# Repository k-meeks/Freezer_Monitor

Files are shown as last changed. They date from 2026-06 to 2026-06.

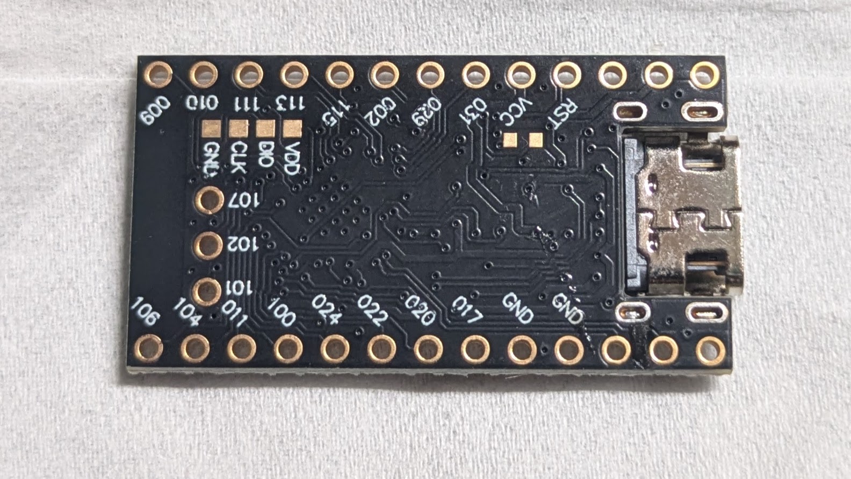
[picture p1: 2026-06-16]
reference-images/PXL_20260615_145303663.jpg

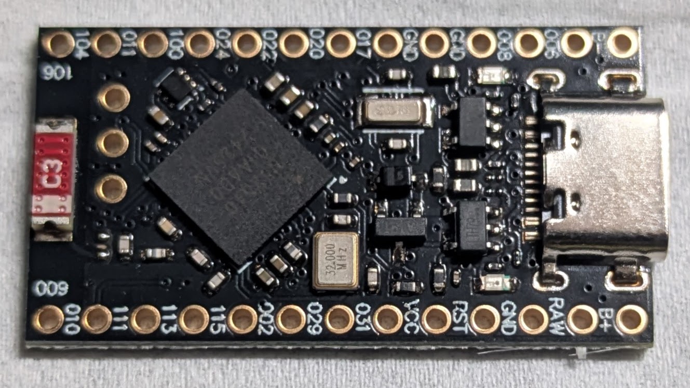
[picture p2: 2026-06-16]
reference-images/PXL_20260615_145255055.jpg

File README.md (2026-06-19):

# Freezer Monitor

A battery-powered sensor that lives inside a chest freezer and reports temperature to Home Assistant via Bluetooth.

## How it works

1. An **nRF52840** wakes on a timer, reads a **DS18B20** temperature sensor, measures battery voltage via an external resistor divider, and broadcasts both as a **BTHome v2** Bluetooth Low Energy advertisement.
2. **Home Assistant** (with a Bluetooth adapter) picks up the advertisement directly via its built-in BTHome integration — no gateway required if HA has BT access near the freezer.
3. HA exposes temperature and battery as entities for dashboards, automations, and alerting.

Power comes from a single Saft LS14250 cell (Li-SOCl₂, 3.6V, 1/2AA) — non-rechargeable, replaced manually when depleted.

## Status

**Deployed and running live** — board is inside the freezer, waking every 5 minutes, with battery and temperature tracked continuously in HA.

**Range note:** Chest freezer lids significantly attenuate BLE (observed drop from -54 dBm on the desk to -82/-88 dBm inside the freezer). TX power is set to +8 dBm (nRF52840 max) to compensate. The active bridge for range is [linux_bt_proxy](https://github.com/k-meeks/linux_bt_proxy) — a fork running on a Linux host near the freezer that relays BTHome advertisements to HA. Theengs Gateway (`ha-bridge/`) remains an untested fallback if that proxy path ever has issues.

A carrier PCB design is in progress — see [Carrier PCB](#carrier-pcb) below.

---

## Parts list

| Part | Spec / notes |
|---|---|
| nRF52840 board | Teyleten Pro Micro nRF52840 (nice!nano v2 clone, ~$4) |
| Temperature sensor | DS18B20 (waterproof probe recommended for freezer use) |
| Battery | Saft LS14250 — Li-SOCl₂, 3.6V nominal, 1/2AA, **primary/non-rechargeable** |
| Battery holder | 1/2AA holder with leads, or JST pigtail — wire through a connector, not direct solder |
| Pull-up resistor | 4.7kΩ (DS18B20 data line) |
| Divider resistors | 2× ~1MΩ (battery voltage sense) |
| Debug adapter | CP2102 or CH340 USB-to-serial, 3.3V logic (development only) |

---

## Board pinout

The board has two 13-pin header rows. **Pin 1 = end farthest from the USB-C connector. Pin 13 = the B−/B+ battery pad itself.**

```
                    USB-C connector
                         |||
         Left (B− side)       Right (B+ side)
         ──────────────       ───────────────
  13     B−  ←battery−        B+  ←battery+       13
  12     P0.06  Serial1 TX    RAW  (USB rail)      12
  11     P0.08  Serial1 RX    GND                  11
  10     GND                  RST  (reset)         10
   9     GND                  VCC  (unusable on    9
                                    battery only)
   8     P0.17  I2C SDA       P0.31 / A7           8
   7     P0.20  I2C SCL       P0.29 / A5           7
   6     P0.22                P0.02 / A0  ←divider 6
   5     P0.24  ←DS18B20      P1.15                5
   4     P1.00                P1.13  SPI SCK        4
   3     P0.11                P1.11  SPI MISO       3
   2     P1.04                P0.10  NFC2/SPI MOSI  2
   1     P1.06                P0.09  NFC1            1
```

**Known-bad pins — do not use:**
- P0.14, P0.16: hang/crash-loop the board when configured as GPIO
- P0.13: not connected to any header pin on this board
- VCC (right pos 9): reads ~0V when running on battery only

---

## Wiring

### Battery (LS14250)

```
LS14250 +  →  B+  (right side, pos 13)
LS14250 −  →  B−  (left side, pos 13)
```

> **Safety:** The board's onboard charge IC is wired to B+/B−. Li-SOCl₂ cells
> must never receive charge current — this is a fire/rupture hazard.
> **Never connect USB while the LS14250 is wired to B+/B−.**
> Wire the cell through a connector (header pins, JST) so it can be unplugged
> before any USB connection.

---

### DS18B20 temperature sensor

The DS18B20 probe has three wires:

```
Red   (VDD)   →  B+  (right side, pos 13)
Black (GND)   →  B−  (left side, pos 13)
Yellow (data) →  P0.24  (left side, pos 5)

4.7kΩ pull-up resistor between yellow (data) and red (VDD/B+)
  — NOT to GND. The data line must be pulled up to VDD, not ground.
```

The easiest way to install the pull-up: bridge the resistor between the yellow
and red wires right at the point where they enter the board headers.

---

### Battery voltage divider

Two ~1MΩ resistors in series form a voltage divider from B+ to GND. The
midpoint is tapped to an ADC input so the firmware can read battery voltage.

```
B+  (right side, pos 13)
  │
 [1MΩ]
  │
  ├──→  P0.02 / A0  (right side, pos 6)
  │
 [1MΩ]
  │
GND  (left side, pos 9 or 10, or right side pos 11)
```

Practical assembly: twist the two resistors together end-to-end. One free end
goes to B+, the other free end goes to GND, and the junction (where they meet)
goes to P0.02/A0 (right side, pos 6).

Continuous draw: ~1.8µA — negligible against the LS14250's 1200mAh capacity.

---

### Debug serial (development only)

When debugging on battery (USB disconnected), use a CP2102/CH340 USB-to-serial
adapter wired to Serial1:

```
Board TX  (left side, pos 12 / P0.06)  →  Adapter RX
Board GND (left side, pos 9 or 10)     →  Adapter GND
Adapter TX pin                          →  leave disconnected
Adapter power/VCC pin                   →  leave disconnected
```

The adapter gets its own USB connection to the PC. The board stays on battery.
Baud rate: 115200.

---

## Arduino IDE setup

1. **File → Preferences → Additional Boards Manager URLs**, add both:
   - `https://adafruit.github.io/arduino-board-index/package_adafruit_index.json`
   - `https://github.com/jpconstantineau/Community_nRF52_Arduino/releases/latest/download/package_jpconstantineau_boards_index.json`
2. **Boards Manager**: install **Adafruit nRF52**, then **Community Add on Adafruit nrf52 boards**.
3. Select board: **Nice Keyboard's nice!nano** (from the Community package).
4. Install libraries: **OneWire**, **DallasTemperature** (Bluefruit BLE is included with the Adafruit nRF52 core).
5. Open `firmware/freezer_monitor/freezer_monitor.ino`.

---

## Programming workflow

Because B+/B− is the charge IC input, flashing and running on the LS14250
cannot happen at the same time:

1. Disconnect the LS14250 from B+/B−.
2. Connect USB, flash firmware from Arduino IDE.
3. Disconnect USB.
4. Reconnect the LS14250.

To enter the UF2 bootloader manually: double-tap the RST pin (right side,
pos 10) — the onboard LED will fade in/out when the bootloader is active.

---

## Home Assistant setup

1. Ensure HA has Bluetooth hardware (built-in adapter or an ESPHome BT proxy).
2. **Settings → Devices & Services → Add Integration → BTHome**.
3. HA will discover the device (`FreezerMonitor`) within a few seconds.
4. The device exposes: temperature (°C), battery (%), packet ID.

> **Range note:** Chest freezer metal lids significantly attenuate BLE signal.
> This deployment uses [linux_bt_proxy](https://github.com/k-meeks/linux_bt_proxy)
> on a nearby Linux host to relay BTHome advertisements to HA. Theengs Gateway
> (`ha-bridge/`) is an untested fallback if that proxy path ever has issues.

---

---

## Carrier PCB

A KiCad carrier board sockets the nRF52840 module into machine-pin headers; all peripherals connect via JST-PH connectors; passives (pull-up, voltage divider, bulk cap) are placed components on the board.

### Bill of materials

PCB-side components (driven by `COMPONENTS` in `gen_freezer_netlist.py`):

| Ref | Qty | Part | Value / spec | Package | Notes |
|---|---|---|---|---|---|
| U1 | 1 | nice!nano nRF52840 (Teyleten clone) | — | THT, 2×13 @ 2.54mm | Socketed, not soldered directly — see machine-pin headers below |
| BT1 | 1 | Battery holder | Keystone 1011, 1/2AA | THT | Polarity-keyed; footprint from SnapEDA (`pcb_build/1011/`) |
| R1, R2 | 2 | Resistor | 1MΩ | 0805 | Battery voltage divider |
| R3 | 1 | Resistor | 4.7kΩ | 0805 | DS18B20 OneWire pull-up to VBAT (not 3.3V) |
| C1 | 1 | Aluminum-polymer radial capacitor | 100µF, low-ESR/low-leakage, ≥6.3V | THT, 8mm dia, 3.5mm lead pitch | Bulk cap at the cell terminals — absorbs BLE TX current spikes against the LS14250's high internal impedance |
| C2 | 1 | Ceramic capacitor | 10nF | 0805 | ADC sense-node decoupling at P0.02 |
| J1 | 1 | JST PH receptacle, 3-pos | B3B-PH-K | THT, 2.00mm pitch | DS18B20 connector |
| J2 | 1 | Pin header, 1×4 | — | THT, 2.54mm | Debug UART: GND / VCC / TX / RX |
| JP1 | 1 | Pin header, 1×2 | — | THT, 2.54mm | Battery isolation jumper — pull before connecting USB |

Off-netlist items needed to finish the build:

| Item | Qty | Notes |
|---|---|---|
| Saft LS14250 cell | 1 | Drops into BT1 — see [Battery (LS14250)](#battery-ls14250) safety note |
| Machine-pin (turned-pin) header strip, 2.54mm | 2× 1×13 | Sockets for U1 so the module can be swapped without desoldering |
| 2.54mm jumper shunt | 1 | For JP1 |
| JST PH 3-pos plug + crimp pins (or pre-crimped pigtail) | 1 | Mates with J1 — only needed if your DS18B20 probe isn't already terminated with one |
| 2-pin or 4-pin 2.54mm header mate | 1 (optional) | For a CP2102/CH340 debug adapter — development only |

All SMD passives are 0805 to keep hand-soldering reasonable without hot air.

### Generating the design files

Regenerate the netlist after any connectivity change:

```
python3 gen_freezer_netlist.py
```

Regenerate the U1 footprint (only needed if the physical module's pinout or dimensions change):

```
python3 gen_nicenano_footprint.py
```

This writes `nice_nano_teyleten.kicad_mod`. To mount U1 rotated 180° (USB/B+/B- end at the opposite side of the board), rotate the footprint instance in pcbnew — that's a placement choice, not something the generator needs to encode.

**Key design decisions baked into the netlist:**
- `JP1` interrupts the battery positive rail — pull the jumper before connecting USB for reprogramming
- `R3` (4.7kΩ) pulls DS18B20 data to VBAT, not 3.3V — sensor is powered from the cell directly
- `C1` (100µF low-ESR electrolytic) at the cell terminals dampens the LS14250's high internal impedance under BLE TX bursts
- `C2` (10nF) decouples the ADC sense node at P0.02
- J2 pin 2 (VCC) is sourced from P1.06 held HIGH — provides a 3.3V logic reference for the CP2102 debug adapter without requiring VCC rail (which is unavailable on battery-only power)

> **Footprint warning:** The netlist uses functional pad names (`B+`, `B-`, `P0.24`, etc.) for U1. Verify these match the exact pad names in `nice!nano clone:nice_nano_teyleten` (or whatever footprint you assign to U1) before importing into KiCad — a mismatch silently drops the connection with no DRC error.

---

## External alerting (planned)

Not yet built — this section documents the intended design so it doesn't get lost between sessions.

**Goal:** when something silently goes wrong (power outage, dead battery, freezer warming up, or HA itself going down), get a phone call or text to a real person — not just a dashboard nobody's looking at.

**Architecture:**

```
nRF52840 (BTHome over BLE)
        │
        ├─ HA host w/ BT  ──┐
        │                   │   POST {site_id, temperature, battery, timestamp}
        └─ ESP32 BLE bridge ┘        (for homes without HA)
                            │
                            ▼
                Alerting API (GCP, TLS + API key)
                            │
                per-site rule evaluation
                            │
                      voip.ms (SMS / call)
```

Designed to scale beyond one freezer in one house — family members could each run their own monitor with their own contact info and thresholds.

**Per-site config** is a hand-edited YAML file, one entry per site, with a variable-length list of alert rules so each owner can have as many or as few thresholds as they want:

```yaml
sites:
  - id: FreezerMonitor-Kyle
    owner: Kyle
    phone: "+1..."
    expected_interval_minutes: 5
    setpoint_c: -18
    rules:
      - {id: missing_10, metric: missing_events, threshold: 10, action: call, repeat: every_1h}
      - {id: temp_5,      metric: temp_delta_c,   threshold: 5,  action: call, repeat: every_1h}
      - {id: battery_30,  metric: battery_pct,    threshold: 30, action: sms,  repeat: once}
      - {id: battery_15,  metric: battery_pct,    threshold: 15, action: sms,  repeat: once}
      - {id: battery_5,   metric: battery_pct,    threshold: 5,  action: call, repeat: every_1h}
```

Each rule fires independently on its own schedule (`once`, or `every_Nh` to keep repeating until resolved), tracked per `(site_id, rule_id)` rather than list position, since rules can be added or reordered later.

**Two alert types:**
- **Heartbeat/watchdog** — missing check-ins, a proxy for power or connectivity failure (there's no direct power sensor). Needs no event log: one `last_seen_at` timestamp per site, compared against `expected_interval_minutes × threshold` cycles.
- **Condition alerts** — temperature too far above setpoint, or battery below a tier threshold. Only meaningful while the device is actively reporting.

**Auth:** the API key lives at the bridge (an HA secret, or baked into ESP32 bridge firmware/config) — never inside the BTHome BLE payload itself, since BLE advertisements broadcast in the clear and there's no spare room in the ~31-byte legacy advertising payload anyway. TLS is required for the API regardless of which bridge is talking to it.

**Still undecided:** exact `/events`/`/check` endpoint contracts, ESP32 bridge firmware specifics, voip.ms integration details, whether to send an "all-clear" notice when an alert resolves.

---

## Repository layout

```
firmware/
  freezer_monitor/     Main Arduino sketch (temperature + BTHome v2 advertisement)
  board_bringup/       Diagnostic sketch used during hardware bring-up (historical)
gen_freezer_netlist.py KiCad netlist generator for the carrier PCB
freezer_monitor.net    Generated KiCad netlist (regenerate via gen_freezer_netlist.py)
ha-bridge/             Theengs Gateway docker-compose (untested fallback; active bridge is linux_bt_proxy, a separate repo)
docs/
  bthome/              BTHome v2 format reference
  hardware/            Board pinout, confirmed quirks, battery notes
  home-assistant/      HA REST API reference
```

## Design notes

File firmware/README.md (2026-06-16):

# Firmware

Arduino sketch for the nRF52840 (Adafruit nRF52 BSP).

Responsibilities:
- Read temperature from the DS18B20 (OneWire / DallasTemperature)
- Read battery voltage/level
- Assemble and send a BTHome v2 BLE advertisement
- Sleep between readings to conserve the 14250 cell

Not yet implemented.

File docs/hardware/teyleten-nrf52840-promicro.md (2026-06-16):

# Teyleten Pro Micro nRF52840 (nice!nano v2 clone)

Saved: 2026-06-15. Compiled from web research — items marked **UNVERIFIED** have not
yet been confirmed against the actual board and should be checked once hardware is
in hand. Move confirmed items to CLAUDE.md's "confirmed quirks" section once tested.

## Identity

- Sold as "Teyleten Robot Pro Micro NRF52840", ~$4, nice!nano v2 form-factor clone.
- Generic family also known as "SuperMini nRF52840" / "Pro Micro nRF52840".
- Zephyr board name for this family: `promicro_nrf52840` (marked "not actively
  maintained" — treat as a loose reference, not gospel).
- Ships with Adafruit's UF2 bootloader.

## Sources

- Pinout notes (community-tested): https://github.com/longrackslabs/teyleten-nrf52840-pinout
- Zephyr board doc: https://docs.zephyrproject.org/latest/boards/others/promicro_nrf52840/doc/index.html
- nice!nano pinout/schematic: https://nicekeyboards.com/docs/nice-nano/pinout-schematic/
- nice!nano battery measurement differences (v1 vs v2): https://github.com/joric/nrfmicro/wiki/Batteries
- Community Arduino board package: https://github.com/jpconstantineau/Community_nRF52_Arduino

## Arduino IDE setup

1. Add both URLs to **File > Preferences > Additional Boards Manager URLs**:
   - `https://adafruit.github.io/arduino-board-index/package_adafruit_index.json` (official Adafruit nRF52 core — required base package)
   - `https://github.com/jpconstantineau/Community_nRF52_Arduino/releases/latest/download/package_jpconstantineau_boards_index.json` (community add-on, adds nice!nano-family boards)
2. In Boards Manager, install **Adafruit nRF52** first, then the community package
   listed as **"Community Add on Adafruit nrf52 boards"** — it appears at the bottom
   of the board list.
3. **CONFIRMED (2026-06-15)**: select **"Nice Keyboard's nice!nano"** (`nice_nano`,
   from `community_nrf52` package v0.1.21). This matches the Teyleten board's
   physical Pro Micro/nice!nano form factor and its `variant.h` defines a `PIN_VBAT`
   (see Battery section below). Build settings: `nice_nano.build.vid=0x239A`,
   `pid=0x00B3`, `upload.maximum_size=815104`.
4. **CONFIRMED**: the board's bootloader reports via USB as VID `0x239A` / PID
   `0x8029` (Tools > Get Board Info shows "Adafruit Feather nRF52840 Express") —
   this exactly matches the `feather52840` entry in the Adafruit package. Despite
   the declared PID differing from `nice_nano`'s (`0x00B3`), both boards use
   `upload.tool=nrfutil` with the same `upload.maximum_size=815104` (same SoftDevice
   S140 6.1.1 layout), so selecting `nice_nano` for build/upload should still work —
   the 1200bps-touch DFU reset doesn't depend on the declared PID matching. If
   upload fails, fall back to building as `feather52840` and only use `nice_nano`
   for the variant.h pin reference.
5. To flash: double-tap the reset button to enter UF2 bootloader mode (status LED
   fades in/out when active), then upload from Arduino IDE (or drag-and-drop the
   `.uf2`).

## Pin numbering convention

From community pin-discovery testing, **confirmed** by the `nice_nano` variant.h
(`_PINNUM(port, pin) = port*32 + pin`):
- `P0.xx` = Arduino pin number `xx` (for xx = 0–31)
- `P1.xx` = Arduino pin number `32 + xx` (for xx = 0–15, i.e. Arduino pins 32–47)

## `nice_nano` variant.h pin reference (confirmed, from installed package v0.1.21)

- `PIN_LED1` (blue) = P0.15 = pin 15 — matches Zephyr `promicro_nrf52840` LED0.
- `PIN_VBAT` = `A7` = pin 31 (P0.31) — see Battery section below.
- Analog: A0-A3 = pins 2-5 (P0.02-P0.05), A4-A7 = pins 28-31 (P0.28-P0.31). `PIN_AREF` = pin 2 (shared with A0).
- Serial1: RX = pin 8 (P0.08), TX = pin 6 (P0.06)
- SPI: MISO = pin 43 (P1.11), MOSI = pin 10 (P0.10), SCK = pin 45 (P1.13)
- Wire: SDA = pin 17 (P0.17), SCL = pin 20 (P0.20)
- NFC1/NFC2 = P0.09 / P0.10 (shared with SPI MOSI when NFC disabled)
- BUTTON_1 = P0.18 marked "unusable: RESET"; BUTTON_2 = P0.19 "no connection" — avoid both.
- `ADC_RESOLUTION` = 14 bits.

## Quick pin reference (silkscreen label -> function)

The silkscreen prints the raw `P0.xx`/`P1.xx` number (with leading zeros, no
"P0." prefix) — e.g. the pin labeled `006` is P0.06. There are no TX/RX/A0-style
function labels printed on the board. For functions used in this project:

| Silkscreen label | Pin / function |
|---|---|
| `B+` | Battery positive (LS14250 +) |
| `B-` | Battery negative (LS14250 -) |
| `006` | P0.06 = `Serial1` TX (debug UART, see below) |
| `008` | P0.08 = `Serial1` RX |
| `007` | P0.07 = OneWire/DS18B20 data (firmware `ONEWIRE_PIN`) |
| `013` | P0.13 = sensor rail power switch (firmware `SENSOR_PWR_PIN`) |
| `031` | P0.31 = A7 = `PIN_VBAT` candidate |
| `VCC` | Regulated 3.3V output |
| `RAW` | Unregulated USB-side rail (not `B+` — don't confuse) |
| `GND` | Ground (multiple) |
| (not exposed) | P0.04 = A2 = alternate VBAT candidate (internal only) |

## Physical board pinout (CONFIRMED 2026-06-15, from board photos)

Top side (USB-C connector), bottom edge of header, right-to-left from the
connector corner: **`B+`**, `RAW`, `GND`, `RST`, `VCC`, `031`, `029`, `002`, ...
Top edge of header, same corner: **`B-`**, `006`, `008`, `GND`, `GND`, `017`, ...

- **`B+` / `B-`** — the battery connection pads. This is the only battery input
  exposed on this board (no separate charge-bypass pad). See Battery section
  below for wiring and safety implications.
- **`RAW`** — unregulated USB-side rail (VBUS-derived), distinct from `B+`. Do
  not confuse the two.
- **`VCC`** — regulated 3.3V output.
- **`031`** = P0.31 = `PIN_VBAT`/A7 (matches variant.h, see Battery voltage
  monitoring section).
- Back side of the board has a 4-pad cluster silkscreened `GND` / `CLK` / (one
  more) / `VDD` near the top edge — likely a debug/SWD header. Not needed for
  current work; useful if firmware debugging via SWD is ever required.

## Physical pin reference (1-13 per side)

Simpler than reading silkscreen labels: each header row has 13 pins. **Pin 1 =
the end farthest from the USB-C connector, pin 13 = the `B-`/`B+` pad itself.**

| Pos | Left side (B- side) | Right side (B+ side) |
|---|---|---|
| 1 | P1.06 — GPIO, no special function | P0.09 — GPIO / NFC1 |
| 2 | P1.04 — GPIO, no special function | P0.10 — GPIO / NFC2, SPI MOSI |
| 3 | P0.11 — GPIO, no special function | P1.11 — SPI MISO |
| 4 | P1.00 — GPIO, no special function | P1.13 — SPI SCK |
| 5 | P0.24 — GPIO, no special function | P1.15 — GPIO, no special function |
| 6 | P0.22 — GPIO, no special function | P0.02 — A0 / AREF |
| 7 | P0.20 — I2C SCL | P0.29 — A5 |
| 8 | P0.17 — I2C SDA | P0.31 — A7 / `PIN_VBAT` |
| 9 | GND | VCC — regulated 3.3V output (USB/RAW-derived, see below) |
| 10 | GND | RST — reset |
| 11 | P0.08 — Serial1 RX | GND |
| 12 | P0.06 — Serial1 TX | RAW — unregulated USB/VBUS rail |
| 13 | **B-** — battery negative | **B+** — battery positive |

Notes:
- P0.15 (`PIN_LED1`, onboard blue LED) is not in this table — it's an onboard
  component, not broken out to a header pin.
- P0.13 also doesn't appear in this table — see "Known special pins" below.
  P0.07 (the original OneWire pin choice) had the same problem; firmware now
  uses P0.24 (left side, position 5) instead.

## Known special pins

- **P0.13** — **CONFIRMED 2026-06-15: not broken out on this board's header at
  all.** `digitalWrite(13, ...)` has no observable effect on `VCC` or any
  header pin (tested via `firmware/board_bringup/board_bringup.ino`: B+ read
  3.6V correctly via multimeter, confirming the meter/ground setup was good,
  but `VCC` stayed near 0V regardless of P0.13 state, and right-side positions
  3-5 all read flat ~45mV noise regardless of P0.13 state). Originally planned
  as `SENSOR_PWR_PIN` for DS18B20 power-gating — dropped; DS18B20 now wires
  directly to `B+`/`B-`.
- **P0.14, P0.16** — **CONFIRMED 2026-06-15: both hang/crash-loop the board**
  as soon as either is configured as GPIO (`pinMode`/`digitalWrite`). Do not
  use either pin.
- **`VCC` (right side, position 9)** — **CONFIRMED 2026-06-15: reads ~0V when
  running off `B+` alone**, regardless of P0.13 state. Likely fed from a
  USB/RAW-derived regulator rather than the battery — not usable as a
  peripheral supply rail on battery power.
- **LED0 = P0.15** (per Zephyr `promicro_nrf52840` board doc) — onboard only,
  not a header pin.

## Battery cell: Saft LS14250 (Li-SOCl2, primary/non-rechargeable)

**CONFIRMED 2026-06-15**: the cell in use is a Saft LS14250 — Lithium Thionyl
Chloride, 1/2AA, 3.6V nominal, primary (non-rechargeable). This is NOT the
Li-ion/LiPo chemistry the onboard charge IC (e.g. BQ24072 on nice!nano-family
boards) expects.

- **Do not let the onboard charge circuit attempt to charge this cell.** Li-SOCl2
  cells can vent, rupture, or ignite under reverse/charge current — this is a
  safety issue, not just a degradation one.
- **CONFIRMED 2026-06-15**: `B+`/`B-` (see "Physical board pinout" above) is the
  only battery input on this board — there is no separate charge-bypass pad.
  Charging only engages when USB power is present (the charge IC is powered from
  VBUS), so the operating rule is: **never plug in USB while the LS14250 is
  connected to B+/B-**. Wire the cell through a connector (JST pigtail + holder
  or a 2-pin header), not a permanent solder joint, so it can be unplugged before
  any USB connection (reprogramming, debugging).
- Wiring: **LS14250 positive lead → `B+`, negative lead → `B-`**. Double-check
  polarity against the cell's own markings before connecting — reverse polarity
  into a charge IC input is its own hazard.

### Debugging while battery-powered

The board's own `Serial` (USB CDC) is only usable when its USB port is
connected — which conflicts with the LS14250-on-`B+`/`B-` rule above. For any
test that needs the battery actually powering the board (e.g. reading
`PIN_VBAT`/A2 against a real battery voltage), use **`Serial1`** (hardware
UART, TX = pin 6/P0.06) wired to a separate 3.3V USB-to-serial adapter
(FTDI/CP2102/CH340): board TX → adapter RX, GND → GND, adapter power pin left
disconnected. The adapter gets its own USB connection to the PC; the board
stays on battery only. `firmware/board_bringup/board_bringup.ino` prints to
both `Serial` and `Serial1` for this reason.

### Programming workflow with the LS14250 connected

Because `B+`/`B-` is the charge IC's input, flashing (which requires USB) and
running on the LS14250 can't happen at the same time. Workflow:

1. Disconnect the LS14250 from `B+`/`B-`.
2. Connect USB, flash firmware.
3. Disconnect USB.
4. Reconnect the LS14250 to run standalone.

**CONFIRMED 2026-06-15**: with only the LS14250 on `B+`/`B-` (no USB, no
firmware flashed yet), the board powered up and a red LED (near a GND pin —
not near the USB connector/charge IC) slow-flashed. This is consistent with
the UF2 bootloader's idle pattern on a board with no application yet, and
confirms `B+`/`B-` wiring powers the board correctly. Not a charge-IC fault
indicator — that would be expected near the USB connector and requires USB
power to occur at all.

Wire the battery through a connector (2-pin header + jumper, or JST pigtail),
not a permanent solder joint, so steps 1 and 4 are quick during development.
- "Recharge" is replaced by "swap the cell" for this project. LS14250 has very
  low self-discharge and is commonly used in devices needing years of service
  from one cell (water meters, alarms), so this is a reasonable tradeoff.
- Li-SOCl2 has a very flat discharge voltage curve until near end-of-life, then
  drops sharply. A voltage-based battery % will read near-100% for most of the
  cell's life and then fall quickly — see [[project-failure-alerting]] for how
  this affects alerting design, and "Battery voltage monitoring" below for how
  it's measured on this board.

## Battery voltage monitoring

- **CONFIRMED 2026-06-15**: `PIN_VBAT`/A7 (P0.31) and A2 (P0.04) are both
  floating/unconnected on this clone — `analogRead()` on either returns pure
  noise uncorrelated with actual battery voltage. There is no internal VBAT
  divider on this board.
- **Solution: external resistor divider.** Two ~1MΩ resistors in series from
  `B+` to `GND`, midpoint wired to `P0.02`/A0 (right side, position 6). Per
  https://devzone.nordicsemi.com/nordic/nordic-blog/b/blog/posts/measuring-lithium-battery-voltage-with-nrf52
  this is the standard approach when no internal divider is present. Adds
  ~1.8µA continuous draw — negligible against the LS14250's capacity.
- Calibrated empirically: with the divider wired, `analogRead(A0)` (14-bit,
  `analogReadResolution(14)`) averaged ~8030 (range 7984-8076) while a
  multimeter read B+ = 3.56V. `BATT_SCALE = 3.56 / 8030 ≈ 0.0004434` V/count —
  see `firmware/freezer_monitor/freezer_monitor.ino`. This single empirical
  constant absorbs both the divider ratio and the ADC reference, so exact
  resistor tolerances and reference voltage don't need to be known.
- `readBatteryVoltage()` averages 8 samples to smooth ~1% ADC noise.
  `readBatteryPercent()` linearly maps `BATT_FULL_V` (3.6V) to `BATT_EMPTY_V`
  (2.0V) — appropriate for the LS14250's flat-then-cliff discharge curve, see
  [[project-failure-alerting]].

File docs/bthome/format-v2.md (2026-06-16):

# BTHome v2 Format Reference

Source: https://bthome.io/format/
Saved: 2026-06-15

## Overview

BTHome v2 is a Bluetooth Low Energy (BLE) advertising format released in November 2022. The format enables devices to transmit sensor data and events through BLE advertisements using a standardized packet structure.

## BLE Packet Structure

BLE packets consist of four components: preamble (1 octet), access address (4 octets), Protocol Data Unit (PDU) (2-257 octets), and Cyclic Redundancy Check (CRC) (3 octets). The actual data transmission occurs within the PDU payload.

## Advertising Payload Structure

The advertising payload comprises one or more **Advertising Data (AD) elements**. Each element contains:
- 1st byte: length (excluding the length byte)
- 2nd byte: AD type specifying the data category
- Remaining bytes: AD data with meaning defined by the AD type

### Required and Recommended Elements

A BTHome advertisement should include:
- **Service Data (16-bit UUID)** - Required, contains actual BTHome data
- **Flags** - Strongly recommended for proper parsing
- **Local Name** - Optional, aids device identification

### Flags Element (`0x01`)

The standard BTHome flags value is `020106`:
- `0x02` = length (2 bytes)
- `0x01` = Flags AD type
- `0x06` = bit pattern `00000110`
  - Bit 1: LE General Discoverable Mode
  - Bit 2: BR/EDR Not Supported

This element is particularly important for passive scanning compatibility with systems like Home Assistant's Bluetooth integration.

### Service Data Element (`0x16`)

Contains the actual BTHome payload with this structure:
- Length byte
- `0x16` = Service Data - 16-bit UUID type
- UUID (16-bit, little-endian)
- BTHome device information byte
- One or more measurements

### Local Name Elements

Optional AD elements for device identification:
- `0x08` = Shortened local name
- `0x09` = Complete local name

Example: `0B094449592D73656E736F72` decodes to "DIY-sensor"

## BTHome Data Format

BTHome service data contains three components:

### UUID Identifier

The 16-bit UUID `0xFCD2` (read in reverse byte order) identifies BTHome messages. This UUID is sponsored by Allterco Robotics (Shelly manufacturer) and is free to use under their license.

### Device Information Byte

The first byte after the UUID encodes device capabilities:

| Bit(s) | Field | Values |
|---|---|---|
| 0 | Encryption flag | 0 = unencrypted, 1 = encrypted |
| 1 | Reserved | — |
| 2 | Trigger-based device flag | 0 = regular intervals, 1 = irregular intervals |
| 3-4 | Reserved | — |
| 5-7 | BTHome version | `010` = version 2 |

Example analysis of `0x40` (binary `01000000`):
- Bit 0: `0` = no encryption
- Bit 2: `0` = regular data updates
- Bits 5-7: `010` = BTHome Version 2

### Measurements

Measurements follow the device information byte, each containing:
- Object ID (1 byte) - specifies measurement type
- Data (1-4 bytes) - value in little-endian format
- Factor - multiplier to achieve proper scale

**Important ordering rule**: Object IDs must appear in numerical order (low to high) to ensure backward compatibility with older receivers.

## Supported Sensor Data Types

### Temperature Measurements

| Object ID | Format | Factor | Unit |
|---|---|---|---|
| `0x02` | sint16 (2 bytes) | 0.01 | °C |
| `0x45` | sint16 (2 bytes) | 0.1 | °C |
| `0x57` | sint8 (1 byte) | 1 | °C |
| `0x58` | sint8 (1 byte) | 0.35 | °C |

Example: `02C409` = 2500 × 0.01 = 25.00°C

### Humidity Measurements

| Object ID | Format | Factor | Unit |
|---|---|---|---|
| `0x03` | uint16 (2 bytes) | 0.01 | % |
| `0x2E` | uint8 (1 byte) | 1 | % |

Example: `03BF13` = 5055 × 0.01 = 50.55%

### Battery and Power

| Object ID | Format | Factor | Unit |
|---|---|---|---|
| `0x01` | uint8 (1 byte) | 1 | % |
| `0x0B` | uint24 (3 bytes) | 0.01 | W |
| `0x0C` | uint16 (2 bytes) | 0.001 | V |
| `0x43` | uint16 (2 bytes) | 0.001 | A |
| `0x5C` | sint32 (4 bytes) | 0.01 | W |
| `0x5D` | sint16 (2 bytes) | 0.001 | A |
| `0x4A` | uint16 (2 bytes) | 0.1 | V |

### Environmental Sensors

| Object ID | Property | Format | Factor | Unit |
|---|---|---|---|---|
| `0x04` | pressure | uint24 (3 bytes) | 0.01 | hPa |
| `0x05` | illuminance | uint24 (3 bytes) | 0.01 | lx |
| `0x08` | dewpoint | sint16 (2 bytes) | 0.01 | °C |
| `0x0D` | pm2.5 | uint16 (2 bytes) | 1 | ug/m3 |
| `0x0E` | pm10 | uint16 (2 bytes) | 1 | ug/m3 |
| `0x12` | CO2 | uint16 (2 bytes) | 1 | ppm |
| `0x13` | TVOC | uint16 (2 bytes) | 1 | ug/m3 |
| `0x14` | moisture | uint16 (2 bytes) | 0.01 | % |
| `0x2F` | moisture | uint8 (1 byte) | 1 | % |
| `0x56` | conductivity | uint16 (2 bytes) | 1 | µS/cm |

### Motion and Acceleration

| Object ID | Property | Format | Factor | Unit |
|---|---|---|---|---|
| `0x51` | acceleration | uint16 (2 bytes) | 0.001 | m/s² |
| `0x63` | acceleration (signed) | sint32 (4 bytes) | 0.000001 | m/s² |
| `0x52` | gyroscope | uint16 (2 bytes) | 0.001 | °/s |

### Volume and Mass

| Object ID | Property | Format | Factor | Unit |
|---|---|---|---|---|
| `0x06` | mass (kg) | uint16 (2 bytes) | 0.01 | kg |
| `0x07` | mass (lb) | uint16 (2 bytes) | 0.01 | lb |
| `0x47` | volume | uint16 (2 bytes) | 0.1 | L |
| `0x48` | volume | uint16 (2 bytes) | 1 | mL |
| `0x49` | volume flow rate | uint16 (2 bytes) | 0.001 | m3/hr |
| `0x4E` | volume | uint32 (4 bytes) | 0.001 | L |
| `0x4F` | water | uint32 (4 bytes) | 0.001 | L |
| `0x55` | volume storage | uint32 (4 bytes) | 0.001 | L |

### Energy and Utilities

| Object ID | Property | Format | Factor | Unit |
|---|---|---|---|---|
| `0x0A` | energy | uint24 (3 bytes) | 0.001 | kWh |
| `0x4B` | gas | uint24 (3 bytes) | 0.001 | m3 |
| `0x4C` | gas | uint32 (4 bytes) | 0.001 | m3 |
| `0x4D` | energy | uint32 (4 bytes) | 0.001 | kWh |

### Speed, Distance, and Rotation

| Object ID | Property | Format | Factor | Unit |
|---|---|---|---|---|
| `0x3F` | rotation | sint16 (2 bytes) | 0.1 | ° |
| `0x40` | distance (mm) | uint16 (2 bytes) | 1 | mm |
| `0x41` | distance (m) | uint16 (2 bytes) | 0.1 | m |
| `0x44` | speed | uint16 (2 bytes) | 0.01 | m/s |
| `0x5E` | direction | uint16 (2 bytes) | 0.01 | ° |
| `0x5F` | precipitation | uint16 (2 bytes) | 0.1 | mm |
| `0x61` | rotational speed | uint16 (2 bytes) | 1 | rpm |
| `0x62` | speed (signed) | sint32 (4 bytes) | 0.000001 | m/s |

### Counters

| Object ID | Format | Factor | Unit |
|---|---|---|---|
| `0x09` | uint8 (1 byte) | 1 | — |
| `0x3D` | uint16 (2 bytes) | 1 | — |
| `0x3E` | uint32 (4 bytes) | 1 | — |
| `0x59` | sint8 (1 byte) | 1 | — |
| `0x5A` | sint16 (2 bytes) | 1 | — |
| `0x5B` | sint32 (4 bytes) | 1 | — |

### Special Types

#### Timestamp (`0x50`)

Unix epoch time (seconds since 1970-01-01 00:00:00 UTC) as uint32 (4 bytes). Example: `0x5D396164` = 1684093277 seconds = 2023-05-14 19:41:17 UTC

#### Text (`0x53`)

Variable length UTF-8 encoded text. Format: Object ID + length byte + text data. Example: `0x530C48656C6C6F20576F726C6421` = "Hello World!" (12 bytes)

#### Raw (`0x54`)

Variable length raw binary data. Format: Object ID + length byte + hex data. Reported as hexadecimal string.

#### Light Level (`0x64`)

uint8 with discrete values: 0 = dark, 1 = twilight, 2 = bright

#### Channel (`0x60`)

uint8 (1 byte), factor 1

#### Settings Revision (`0x65`)

uint8 (1 byte), factor 1

### Duration

| Object ID | Format | Factor | Unit |
|---|---|---|---|
| `0x42` | uint24 (3 bytes) | 0.001 | s |

### UV Index

| Object ID | Format | Factor | Unit |
|---|---|---|---|
| `0x46` | uint8 (1 byte) | 0.1 | — |

### Multiple Measurements

Multiple measurements of the same type can be included in a single advertisement. Each additional measurement of the same type receives a numeric suffix (temperature_2, temperature_3, etc.). Maintain consistent ordering across advertisements to prevent incorrect assignment.

## Binary Sensor Data

Binary sensors transmit uint8 values: `0` = off/false, `1` = on/true

| Object ID | Property | Meaning (0/1) |
|---|---|---|
| `0x0F` | generic boolean | Off / On |
| `0x10` | power | Off / On |
| `0x11` | opening | Closed / Open |
| `0x15` | battery | Normal / Low |
| `0x16` | battery charging | Not Charging / Charging |
| `0x17` | carbon monoxide | Not detected / Detected |
| `0x18` | cold | Normal / Cold |
| `0x19` | connectivity | Disconnected / Connected |
| `0x1A` | door | Closed / Open |
| `0x1B` | garage door | Closed / Open |
| `0x1C` | gas | Clear / Detected |
| `0x1D` | heat | Normal / Hot |
| `0x1E` | light | No light / Light detected |
| `0x1F` | lock | Locked / Unlocked |
| `0x20` | moisture | Dry / Wet |
| `0x21` | motion | Clear / Detected |
| `0x22` | moving | Not moving / Moving |
| `0x23` | occupancy | Clear / Detected |
| `0x24` | plug | Unplugged / Plugged in |
| `0x25` | presence | Away / Home |
| `0x26` | problem | OK / Problem |
| `0x27` | running | Not Running / Running |
| `0x28` | safety | Unsafe / Safe |
| `0x29` | smoke | Clear / Detected |
| `0x2A` | sound | Clear / Detected |
| `0x2B` | tamper | Off / On |
| `0x2C` | vibration | Clear / Detected |
| `0x2D` | window | Closed / Open |

## Events

Devices can transmit events representing user actions or state changes. Event support is available in Home Assistant 2023.5 and higher.

### Button Events (`0x3A`)

| Event ID | Event Type |
|---|---|
| `0x00` | None |
| `0x01` | press |
| `0x02` | double_press |
| `0x03` | triple_press |
| `0x04` | long_press |
| `0x05` | long_double_press |
| `0x06` | long_triple_press |
| `0x80` | hold_press |

Examples: `3A00` = no event, `3A01` = press, `3A04` = long_press

### Command Events (`0x3B`)

| Event ID | Type | Parameter |
|---|---|---|
| `0x00` | off | — |
| `0x01` | on | — |
| `0x02` | toggle | — |
| `0x03` | step up | number of steps |
| `0x04` | step down | number of steps |

Format: Object ID + argument length byte + opcode byte + argument bytes

Example: `0x3B010305` = step up 5 steps
- `0x3B` = command object
- `0x01` = 1 byte argument length
- `0x03` = opcode (step up)
- `0x05` = 5 steps

Commands should be encrypted to prevent unauthorized observation or spoofing.

### Dimmer Events (`0x3C`)

| Event ID | Type | Parameter |
|---|---|---|
| `0x00` | None | — |
| `0x01` | rotate left | number of steps |
| `0x02` | rotate right | number of steps |

Examples: `3C0103` = rotate left 3 steps, `3C020A` = rotate right 10 steps

### Multiple Events

Multiple events of the same type can be transmitted by concatenating them. The `0x00` (None) event is useful for multi-button devices when reporting only specific button presses.

Example: `3A003A01` = no event for first button, press event for second button

## Device Information

Optional fields for device identification and management:

| Object ID | Property | Format | Example | Result |
|---|---|---|---|---|
| `0xF0` | device type id | uint16 (2 bytes) | `F00100` | 1 |
| `0xF1` | firmware version | uint32 (4 bytes) | `F100010204` | 4.2.1.0 |
| `0xF2` | firmware version | uint24 (3 bytes) | `F2000106` | 6.1.0 |

Device type IDs distinguish between different device models. Firmware versions support two formats: `0.0.0.1` (32-bit) or `0.0.1` (24-bit).

## Miscellaneous Data

### Packet ID (`0x00`)

Optional uint8 (1 byte) ranging from 0-255. Increments with each data change to filter duplicate advertisements. Receivers should only process packets with different IDs than the previous advertisement. Many home automation systems already filter unchanged data, making this optional.

Example: `0009` = packet ID 9

## Encryption

BTHome supports AES encryption in CCM mode using a pre-shared key for security-sensitive data. Unencrypted advertisements can be read by any nearby Bluetooth listener.

### Key Requirements

- 16 bytes (32 hexadecimal characters) long
- Pre-shared between sender and receiver
- Enables encrypted data to remain unreadable without the key

### Implementation Guidance

When the encryption flag (bit 0 in device information byte) is set to `1`, data is encrypted. Detailed encryption specifications are available on the BTHome encryption documentation page.

## Example Payload Analysis

Complete example: `020106 0B094449592D73656E736F72 0A16D2FC4002C40903BF13`

### Flags Element
`020106`
- Length: 2, Type: Flags (`0x01`), Value: `06` (LE General Discoverable Mode + BR/EDR Not Supported)

### Local Name Element
`0B094449592D73656E736F72`
- Length: 11, Type: Complete Local Name (`0x09`), Name: "DIY-sensor"

### Service Data Element
`0A16D2FC4002C40903BF13`
- Length: 10, Type: Service Data - 16-bit UUID (`0x16`)
- Data: `D2FC4002C40903BF13`

#### BTHome Data Breakdown
- UUID: `D2FC` (reversed = `0xFCD2`)
- Device Info: `40` (unencrypted, regular intervals, version 2)
- Temperature: `02C409` = 25.00°C
- Humidity: `03BF13` = 50.55%

## Standards and References

- BLE packet format specifications available from Bluetooth SIG
- BTHome UUID sponsored by Allterco Robotics (Shelly)
- Standardized AD types from Generic Access Profile specifications
- Full example payloads for each data type available on GitHub

## Credits

BTHome is created by Ernst Klamer with contributions from Victor and Paulus Schoutsen, sponsored by Shelly.

---

## Relevant fields for this project (freezer temp monitor)

- Temperature: object ID `0x02`, sint16, factor 0.01, °C — best resolution for a freezer (range well within sint16, e.g. -20.00°C = -2000 = 0xF830)
- Battery: object ID `0x01`, uint8, factor 1, % — for low-battery alerting (see project failure-alerting notes)
- Packet ID: object ID `0x00`, uint8 — optional but cheap, useful for diagnosing missed/duplicate advertisements
- Object IDs must be ascending: `0x00` (packet id) < `0x01` (battery) < `0x02` (temperature) — so payload order should be packet id, battery, then temperature

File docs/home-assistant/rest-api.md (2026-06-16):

# Home Assistant REST API Reference

Source: https://developers.home-assistant.io/docs/api/rest/
Saved: 2026-06-14

## Overview

Home Assistant provides a RESTful API on the same port as the web frontend (default port is port 8123). The API accepts and returns only JSON-encoded objects.

### Prerequisites

- If the frontend integration isn't active, add the API integration to `configuration.yaml`
- All API calls require the header: `Authorization: Bearer TOKEN`
- Obtain a Long-Lived Access Token from your profile at `http://IP_ADDRESS:8123/profile`

### Base Endpoints

- Control interface: `http://IP_ADDRESS:8123/`
- RESTful API: `http://IP_ADDRESS:8123/api/`

## Client Examples

### Using cURL
```bash
curl \
  -H "Authorization: Bearer TOKEN" \
  -H "Content-Type: application/json" \
  http://IP_ADDRESS:8123/ENDPOINT
```

### Using Python
```python
from requests import get

url = "http://localhost:8123/ENDPOINT"
headers = {
    "Authorization": "Bearer TOKEN",
    "content-type": "application/json",
}

response = get(url, headers=headers)
print(response.text)
```

### Using RESTful Command Integration
```yaml
turn_light_on:
  url: http://localhost:8123/api/states/light.study_light
  method: POST
  headers:
    authorization: 'Bearer TOKEN'
    content-type: 'application/json'
  payload: '{"state":"on"}'
```

## Status Codes

Successful calls return 200 or 201. Other possible codes:
- 400 (Bad Request)
- 401 (Unauthorized)
- 404 (Not Found)
- 405 (Method Not Allowed)

---

## API Endpoints

### GET `/api/`

Returns a message if the API is operational.

**Response:**
```json
{
  "message": "API running."
}
```

**cURL:**
```bash
curl \
  -H "Authorization: Bearer TOKEN" \
  -H "Content-Type: application/json" \
  http://localhost:8123/api/
```

**Note:** make sure you include the trailing `/`, the full path is `/api/`, NOT `/api`

---

### GET `/api/config`

Returns the current configuration as JSON.

**Response Example:**
```json
{
   "components":[
      "sensor.cpuspeed",
      "frontend",
      "config.core",
      "http",
      "map",
      "api",
      "sun",
      "config",
      "discovery",
      "conversation",
      "recorder",
      "group",
      "sensor",
      "websocket_api",
      "automation",
      "config.automation",
      "config.customize"
   ],
   "config_dir":"/home/ha/.homeassistant",
   "elevation":510,
   "latitude":45.8781529,
   "location_name":"Home",
   "longitude":8.458853651,
   "time_zone":"Europe/Zurich",
   "unit_system":{
      "length":"km",
      "mass":"g",
      "temperature":"°C",
      "volume":"L"
   },
   "version":"0.56.2",
   "whitelist_external_dirs":[
      "/home/ha/.homeassistant/www",
      "/home/ha/.homeassistant/"
   ]
}
```

**cURL:**
```bash
curl \
  -H "Authorization: Bearer TOKEN" \
  -H "Content-Type: application/json" \
  http://localhost:8123/api/config
```

---

### GET `/api/components`

Returns a list of currently loaded components.

**Response Example:**
```json
[
  "currentcost.sensor",
  "tapo.switch",
  "tuya_ble.sensor",
  "backup",
  "ble_monitor.binary_sensor",
  "localtuya.remote",
  "logger",
  "http",
  "hacs",
  "cast",
  "device_tracker",
  "upnp.binary_sensor",
  "notify",
  "person",
  "..."
]
```

**cURL:**
```bash
curl \
  -H "Authorization: Bearer TOKEN" \
  -H "Content-Type: application/json" \
  http://localhost:8123/api/components
```

---

### GET `/api/events`

Returns an array of event objects. Each event object contains event name and listener count.

**Response Example:**
```json
[
    {
      "event": "state_changed",
      "listener_count": 5
    },
    {
      "event": "time_changed",
      "listener_count": 2
    }
]
```

**cURL:**
```bash
curl \
  -H "Authorization: Bearer TOKEN" \
  -H "Content-Type: application/json" \
  http://localhost:8123/api/events
```

---

### GET `/api/services`

Returns an array of service objects. Each object contains the domain and which services it contains.

**Response Example:**
```json
[
    {
      "domain": "browser",
      "services": [
        "browse_url"
      ]
    },
    {
      "domain": "keyboard",
      "services": [
        "volume_up",
        "volume_down"
      ]
    }
]
```

**cURL:**
```bash
curl \
  -H "Authorization: Bearer TOKEN" \
  -H "Content-Type: application/json" \
  http://localhost:8123/api/services
```

---

### GET `/api/history/period/<timestamp>`

Returns an array of state changes in the past. Each object contains further details for the entities.

The `<timestamp>` (format: `YYYY-MM-DDThh:mm:ssTZD`) is optional and defaults to 1 day before request time.

**Required Parameters:**
- `filter_entity_id=<entity_ids>` — filter by one or more entities (comma-separated)

**Optional Parameters:**
- `end_time=<timestamp>` — choose period end (URL encoded; defaults to 1 day)
- `minimal_response` — return only `last_changed` and `state` (faster)
- `no_attributes` — skip attributes from database (faster)
- `significant_changes_only` — return only significant state changes

**Response Example (without minimal_response):**
```json
[
    [
        {
            "attributes": {
                "friendly_name": "Weather Temperature",
                "unit_of_measurement": "°C"
            },
            "entity_id": "sensor.weather_temperature",
            "last_changed": "2016-02-06T22:15:00+00:00",
            "last_updated": "2016-02-06T22:15:00+00:00",
            "state": "-3.9"
        },
        {
            "attributes": {
                "friendly_name": "Weather Temperature",
                "unit_of_measurement": "°C"
            },
            "entity_id": "sensor.weather_temperature",
            "last_changed": "2016-02-06T22:15:00+00:00",
            "last_updated": "2016-02-06T22:15:00+00:00",
            "state": "-1.9"
        }
    ]
]
```

**Response Example (with minimal_response):**
```json
[
    [
        {
            "attributes": {
                "friendly_name": "Weather Temperature",
                "unit_of_measurement": "°C"
            },
            "entity_id": "sensor.weather_temperature",
            "last_changed": "2016-02-06T22:15:00+00:00",
            "last_updated": "2016-02-06T22:15:00+00:00",
            "state": "-3.9"
        },
        {
            "last_changed": "2016-02-06T22:20:00+00:00",
            "state": "-2.9"
        },
        {
            "last_changed": "2016-02-06T22:22:00+00:00",
            "state": "-2.2"
        },
        {
            "attributes": {
                "friendly_name": "Weather Temperature",
                "unit_of_measurement": "°C"
            },
            "entity_id": "sensor.weather_temperature",
            "last_changed": "2016-02-06T22:25:00+00:00",
            "last_updated": "2016-02-06T22:25:00+00:00",
            "state": "-1.9"
        }
    ]
]
```

**cURL Examples:**

Past day history (default):
```bash
curl \
  -H "Authorization: Bearer TOKEN" \
  -H "Content-Type: application/json" \
  "http://localhost:8123/api/history/period?filter_entity_id=sensor.temperature"
```

Minimal history with manual start date:
```bash
curl \
  -H "Authorization: Bearer TOKEN" \
  -H "Content-Type: application/json" \
  "http://localhost:8123/api/history/period/2023-09-04T00:00:00+02:00?filter_entity_id=sensor.temperature,sensor.kitchen_temperature&minimal_response"
```

History with specific date range:
```bash
curl \
  -H "Authorization: Bearer TOKEN" \
  -H "Content-Type: application/json" \
  "http://localhost:8123/api/history/period/2021-09-04T00%3A00%3A00%2B02%3A00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"
```

---

### GET `/api/logbook/<timestamp>`

Returns an array of logbook entries.

The `<timestamp>` (format: `YYYY-MM-DDThh:mm:ssTZD`) is optional and defaults to 1 day before request time.

**Optional Parameters:**
- `entity=<entity_id>` — filter by one entity
- `end_time=<timestamp>` — choose period end (URL encoded)

**Response Example:**
```json
[
  {
    "context_user_id": null,
    "domain": "alarm_control_panel",
    "entity_id": "alarm_control_panel.area_001",
    "message": "changed to disarmed",
    "name": "Security",
    "when": "2020-06-20T16:44:26.127295+00:00"
  },
  {
    "context_user_id": null,
    "domain": "homekit",
    "entity_id": "alarm_control_panel.area_001",
    "message": "send command alarm_arm_night for Security",
    "name": "HomeKit",
    "when": "2020-06-21T02:59:05.759645+00:00"
  },
  {
    "context_user_id": null,
    "domain": "alarm_control_panel",
    "entity_id": "alarm_control_panel.area_001",
    "message": "changed to armed_night",
    "name": "Security",
    "when": "2020-06-21T02:59:06.015463+00:00"
  }
]
```

**cURL Examples:**

Basic logbook:
```bash
curl \
  -H "Authorization: Bearer TOKEN" \
  -H "Content-Type: application/json" \
  http://localhost:8123/api/logbook/2016-12-29T00:00:00+02:00
```

With end time and entity filter:
```bash
curl \
  -H "Authorization: Bearer TOKEN" \
  -H "Content-Type: application/json" \
  "http://localhost:8123/api/logbook/2016-12-29T00:00:00+02:00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"
```

With end time only:
```bash
curl \
  -H "Authorization: Bearer TOKEN" \
  -H "Content-Type: application/json" \
  "http://localhost:8123/api/logbook/2016-12-29T00:00:00+02:00?end_time=2099-12-31T00%3A00%3A00%2B02%3A00"
```

---

### GET `/api/states`

Returns an array of state objects. Each state has the following attributes: `entity_id`, `state`, `last_changed` and `attributes`.

**Response Example:**
```json
[
    {
        "attributes": {},
        "entity_id": "sun.sun",
        "last_changed": "2016-05-30T21:43:32.418320+00:00",
        "state": "below_horizon"
    },
    {
        "attributes": {},
        "entity_id": "process.Dropbox",
        "last_changed": "22016-05-30T21:43:32.418320+00:00",
        "state": "on"
    }
]
```

**cURL:**
```bash
curl \
  -H "Authorization: Bearer TOKEN" \
  -H "Content-Type: application/json" \
  http://localhost:8123/api/states
```

---

### GET `/api/states/<entity_id>`

Returns a state object for specified `entity_id`. Returns 404 if not found.

**Response Example:**
```json
{
   "attributes":{
      "azimuth":336.34,
      "elevation":-17.67,
      "friendly_name":"Sun",
      "next_rising":"2016-05-31T03:39:14+00:00",
      "next_setting":"2016-05-31T19:16:42+00:00"
   },
   "entity_id":"sun.sun",
   "last_changed":"2016-05-30T21:43:29.204838+00:00",
   "last_updated":"2016-05-30T21:50:30.529465+00:00",
   "state":"below_horizon"
}
```

**cURL:**
```bash
curl \
  -H "Authorization: Bearer TOKEN" \
  -H "Content-Type: application/json" \
  http://localhost:8123/api/states/sensor.kitchen_temperature
```

---

### GET `/api/error_log`

Retrieve all errors logged during the current session of Home Assistant as a plaintext response.

**Response Example:**
```
15-12-20 11:02:50 homeassistant.components.recorder: Found unfinished sessions
15-12-20 11:03:03 netdisco.ssdp: Error fetching description at http://192.168.1.1:8200/rootDesc.xml
15-12-20 11:04:36 homeassistant.components.alexa: Received unknown intent HelpIntent
```

**cURL:**
```bash
curl \
  -H "Authorization: Bearer TOKEN" \
  -H "Content-Type: application/json" \
  http://localhost:8123/api/error_log
```

---

### GET `/api/camera_proxy/<camera entity_id>`

Returns the data (image) from the specified camera `entity_id`.

**cURL:**
```bash
curl \
  -H "Authorization: Bearer TOKEN" \
  -H "Content-Type: application/json" \
  -o image.jpg \
  "http://localhost:8123/api/camera_proxy/camera.my_sample_camera?time=1462653861261"
```

---

### GET `/api/calendars`

Returns the list of calendar entities.

**Response Example:**
```json
[
  {
    "entity_id": "calendar.holidays",
    "name": "National Holidays"
  },
  {
    "entity_id": "calendar.personal",
    "name": "Personal Calendar"
  }
]
```

**cURL:**
```bash
curl \
  -H "Authorization: Bearer TOKEN" \
  -H "Content-Type: application/json" \
  http://localhost:8123/api/calendars
```

---

### GET `/api/calendars/<calendar entity_id>?start=<timestamp>&end=<timestamp>`

Returns the list of calendar events for the specified calendar `entity_id` between the `start` and `end` times (exclusive).

The events in the response have a `start` and `end` that contain either `dateTime` or `date` for an all day event.

**Response Example:**
```json
[
  {
    "summary": "Cinco de Mayo",
    "start": {
      "date": "2022-05-05"
    },
    "end": {
      "date": "2022-05-06"
    }
  },
  {
    "summary": "Birthday Party",
    "start": {
      "dateTime": "2022-05-06T20:00:00-07:00"
    },
    "end": {
      "dateTime": "2022-05-06T23:00:00-07:00"
    },
    "description": "Don't forget to bring balloons",
    "location": "Brian's House"
  }
]
```

**cURL:**
```bash
curl \
  -H "Authorization: Bearer TOKEN" \
  -H "Content-Type: application/json" \
  "http://localhost:8123/api/calendars/calendar.holidays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"
```

---

### POST `/api/states/<entity_id>`

Updates or creates a state. You can create any state that you want, it does not have to be backed by an entity in Home Assistant.

**Note:** This endpoint sets the representation of a device within Home Assistant and will not communicate with the actual device. To communicate with the device, use the `POST /api/services/<domain>/<service>` endpoint.

Expects a JSON object with at least a state attribute:

**Request Example:**
```json
{
    "state": "below_horizon",
    "attributes": {
        "next_rising":"2016-05-31T03:39:14+00:00",
        "next_setting":"2016-05-31T19:16:42+00:00"
    }
}
```

Returns 200 if entity existed, 201 if new state was created. Response body contains JSON-encoded State object:

**Response Example:**
```json
{
    "attributes": {
        "next_rising":"2016-05-31T03:39:14+00:00",
        "next_setting":"2016-05-31T19:16:42+00:00"
    },
    "entity_id": "sun.sun",
    "last_changed": "2016-05-30T21:43:29.204838+00:00",
    "last_updated": "2016-05-30T21:47:30.533530+00:00",
    "state": "below_horizon"
}
```

**cURL:**
```bash
curl \
  -H "Authorization: Bearer TOKEN" \
  -H "Content-Type: application/json" \
  -d '{"state": "25", "attributes": {"unit_of_measurement": "°C"}}' \
  http://localhost:8123/api/states/sensor.kitchen_temperature
```

**Python Example:**
```python
from requests import post

url = "http://localhost:8123/api/states/sensor.kitchen_temperature"
headers = {"Authorization": "Bearer TOKEN", "content-type": "application/json"}
data = {"state": "25", "attributes": {"unit_of_measurement": "°C"}}

response = post(url, headers=headers, json=data)
print(response.text)
```

---

### POST `/api/events/<event_type>`

Fires an event with `event_type`.

Can pass an optional JSON object as `event_data`:

**Request Example:**
```json
{
    "next_rising":"2016-05-31T03:39:14+00:00"
}
```

Returns a message if successful:

**Response Example:**
```json
{
    "message": "Event download_file fired."
}
```

---

### POST `/api/services/<domain>/<service>`

Calls a service within a specific domain. Will return when the service has been executed.

Can pass an optional JSON object as `service_data`:

**Request Example:**
```json
{
    "entity_id": "light.Ceiling"
}
```

Returns a list of states that changed while the service was executed:

**Response Example (without return_response):**
```json
[
    {
        "attributes": {},
        "entity_id": "sun.sun",
        "last_changed": "2016-05-30T21:43:32.418320+00:00",
        "state": "below_horizon"
    },
    {
        "attributes": {},
        "entity_id": "process.Dropbox",
        "last_changed": "22016-05-30T21:43:32.418320+00:00",
        "state": "on"
    }
]
```

**Response Example (with ?return_response):**
```json
{
    "changed_states": [
        {
            "attributes": {},
            "entity_id": "sun.sun",
            "last_changed": "2024-04-22T20:45:54.418320-04:00",
            "state": "below_horizon"
        },
        {
            "attributes": {},
            "entity_id": "binary_sensor.dropbox",
            "last_changed": "2024-04-22T20:45:54.418320-04:00",
            "state": "on"
        }
    ],
    "service_response": {
        "weather.new_york_forecast": {
            "forecast": [
                {
                    "condition": "clear-night",
                    "datetime": "2024-04-22T20:45:55.173725-04:00",
                    "precipitation_probability": 0,
                    "temperature": null,
                    "templow": 6.0
                },
                {
                    "condition": "rainy",
                    "datetime": "2024-04-23T20:45:55.173756-04:00",
                    "precipitation_probability": 60,
                    "temperature": 16.0,
                    "templow": 4.0
                }
            ]
        }
    }
}
```

**Note:** The result will include any states that changed while the service was being executed, even if their change was the result of something else happening in the system.

If the service supports returning response data, add `?return_response` to the URL.

**Important:** Some services return no data, others optionally return response data, and some always return response data. If you don't use `return_response` when calling a service that must return data, the API will return a 400. Similarly, you will receive a 400 if you use `return_response` when calling a service that doesn't return any data.

**cURL Examples:**

Turn light on:
```bash
curl \
  -H "Authorization: Bearer TOKEN" \
  -H "Content-Type: application/json" \
  -d '{"entity_id": "switch.christmas_lights"}' \
  http://localhost:8123/api/services/switch/turn_on
```

**Python Example:**

Turn light on:
```python
from requests import post

url = "http://localhost:8123/api/services/light/turn_on"
headers = {"Authorization": "Bearer TOKEN"}
data = {"entity_id": "light.study_light"}

response = post(url, headers=headers, json=data)
print(response.text)
```

Send MQTT message:
```bash
curl \
  -H "Content-Type: application/json" \
  -H "Authorization: Bearer TOKEN" \
  -d '{"payload": "OFF", "topic": "home/fridge", "retain": "True"}' \
  http://localhost:8123/api/services/mqtt/publish
```

Retrieve daily weather forecast:
```bash
curl \
  -H "Content-Type: application/json" \
  -H "Authorization: Bearer TOKEN" \
  -d '{"entity_id": "weather.forecast_home", "type": "daily"}' \
  http://localhost:8123/api/services/weather/get_forecasts?return_response
```

---

### POST `/api/template`

Render a Home Assistant template.

**Request Example:**
```json
{
    "template": "Paulus is at {{ states('device_tracker.paulus') }}!"
}
```

Returns the rendered template in plain text:

**Response Example:**
```
Paulus is at work!
```

**cURL:**
```bash
curl \
  -H "Authorization: Bearer TOKEN" \
  -H "Content-Type: application/json" \
  -d '{"template": "It is {{ now() }}!"}' \
  http://localhost:8123/api/template
```

---

### POST `/api/config/core/check_config`

Trigger a check of `configuration.yaml`. No additional data needs to be passed in with this request. Needs config integration enabled.

If successful:

**Response Example:**
```json
{
    "errors": null,
    "result": "valid"
}
```

If unsuccessful, the errors attribute lists what caused failure:

**Response Example:**
```json
{
    "errors": "Integration not found: frontend:",
    "result": "invalid"
}
```

---

### POST `/api/intent/handle`

Handle an intent.

You must add `intent:` to your `configuration.yaml` to enable this endpoint.

**cURL Example:**
```bash
curl \
  -H "Authorization: Bearer TOKEN" \
  -H 'Content-Type: application/json' \
  -d '{ "name": "SetTimer", "data": { "seconds": "30" } }' \
  http://localhost:8123/api/intent/handle
```

---

### DELETE `/api/states/<entity_id>`

Deletes an entity with the specified `entity_id`.

**cURL:**
```bash
curl \
  -X DELETE \
  -H "Authorization: Bearer TOKEN" \
  -H "Content-Type: application/json" \
  http://localhost:8123/api/states/sensor.kitchen_temperature
```

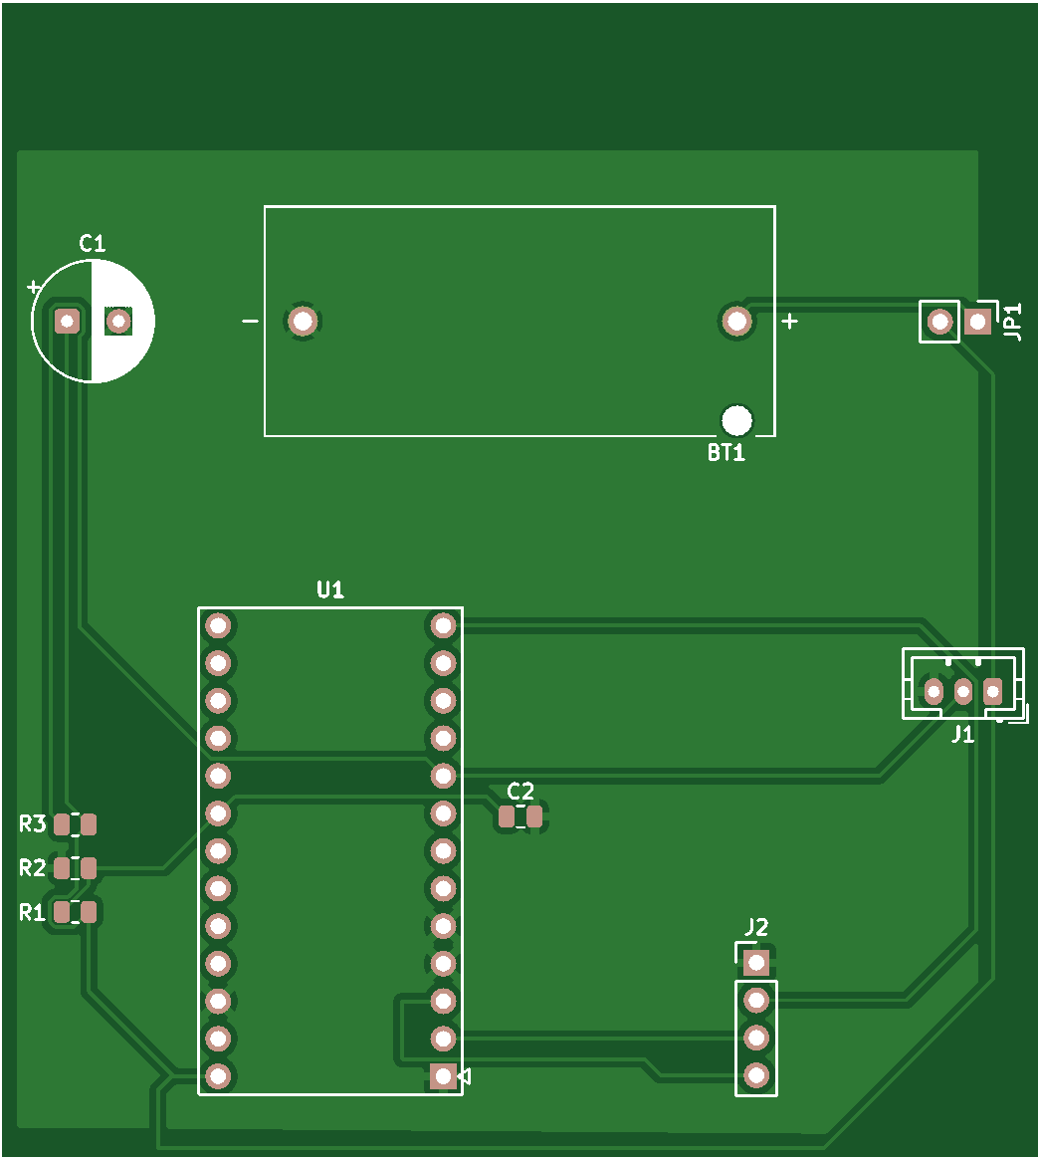
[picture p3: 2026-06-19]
sm_green_top.png

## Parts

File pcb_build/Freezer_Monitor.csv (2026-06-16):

Id | Designator | Footprint | Quantity | Designation | Supplier and ref
1 | BT1 | BAT_1011 | 1 | LS14250
2 | C1 | CP_Radial_D8.0mm_P3.50mm | 1 | 100uF
3 | C2 | C_0805_2012Metric | 1 | 10nF
4 | J1 | JST_PH_B3B-PH-K_1x03_P2.00mm_Vertical | 1 | DS18B20
5 | J2 | PinHeader_1x04_P2.54mm_Vertical | 1 | SERIAL
6 | JP1 | PinHeader_1x02_P2.54mm_Vertical | 1 | BATT
7 | R1, R2 | R_0805_2012Metric | 2 | 1M
8 | R3 | R_0805_2012Metric | 1 | 4.7k
9 | U1 | nice_nano_teyleten_usb_flipped | 1 | nice!nano nRF52840

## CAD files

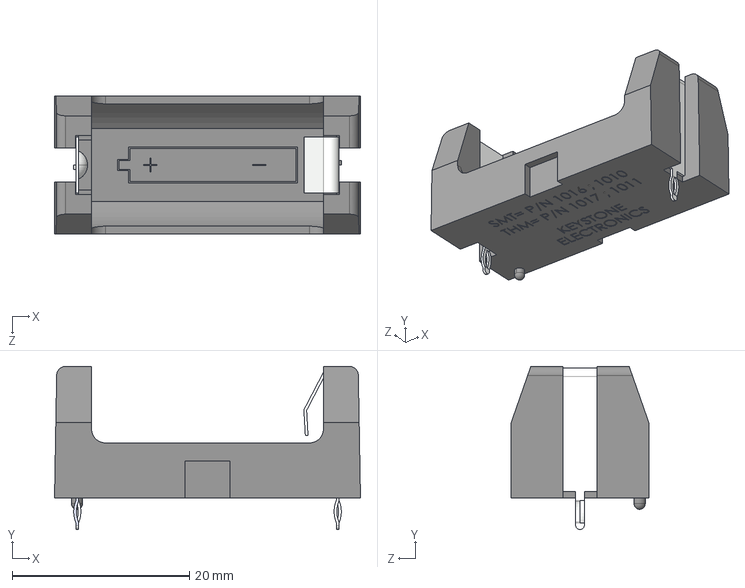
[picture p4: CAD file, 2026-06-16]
pcb_build/1011/1011.step
34.5 x 18.4 x 15.5 mm

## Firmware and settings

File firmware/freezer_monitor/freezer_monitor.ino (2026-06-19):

/*
 * Freezer Monitor - nRF52840 + DS18B20 + BTHome v2 over BLE
 *
 * Board: Teyleten Pro Micro nRF52840 (nice!nano v2 clone)
 *   - Arduino core: Adafruit nRF52 + Community Add-on (nice!nano-family board)
 *   - Pin notes: docs/hardware/teyleten-nrf52840-promicro.md
 *
 * Cycle: wake -> read DS18B20 -> read battery -> advertise BTHome v2 packet
 *        -> sleep -> repeat
 *
 * BTHome v2 reference: docs/bthome/format-v2.md
 */

#include <bluefruit.h>
#include <OneWire.h>
#include <DallasTemperature.h>

// ---------------------------------------------------------------------------
// Pin configuration
// P0.xx = Arduino pin xx (0-31); P1.xx = Arduino pin (32 + xx) - confirmed via
// the nice_nano variant.h. Avoid P0.14 / P0.16 (reported problematic, UNVERIFIED)
// and P0.18/P0.19 (RESET / no connection per variant.h).
// ---------------------------------------------------------------------------
#define ONEWIRE_PIN     24  // P0.24 (left side, position 5) - DS18B20 data line (needs 4.7k pull-up to 3V3)

// Battery voltage divider: two 1M resistors in series from B+ to GND, midpoint
// to P0.02/A0 (right side, position 6). CONFIRMED 2026-06-15 that PIN_VBAT
// (P0.31) and A2 (P0.04) are floating/unusable on this clone - this external
// divider replaces that approach.
#define BATT_ADC_PIN    A0  // P0.02

// Empirical scale factor: B+ measured at 3.56V via multimeter while
// analogRead(BATT_ADC_PIN) averaged ~8030 (range 7984-8076). BATT_SCALE =
// 3.56 / 8030. Good enough given the LS14250's flat discharge curve - we're
// mainly looking for the late-life voltage cliff, not precise %.
#define BATT_SCALE      0.0004434f

// LS14250 (Li-SOCl2) discharge curve is flat near its 3.6V nominal voltage for
// most of its life, then drops sharply near end-of-life. A linear map between
// these two points will read near 100% for most of the cell's life and fall
// quickly once the cliff is reached - which is the useful signal for failure
// alerting (see CLAUDE.md / docs/hardware notes).
#define BATT_FULL_V     3.6f   // nominal fresh-cell voltage -> 100%
#define BATT_EMPTY_V    2.0f   // datasheet end-of-discharge voltage -> 0%

// ---------------------------------------------------------------------------
// Timing
// ---------------------------------------------------------------------------
#define SLEEP_INTERVAL_MS     (5UL * 60UL * 1000UL)   // 5 minutes
#define ADVERTISE_DURATION_MS 2000                   // how long to advertise each cycle

// ---------------------------------------------------------------------------
// BTHome v2 (see docs/bthome/format-v2.md)
// Object IDs must stay in ascending order: packet id (0x00) < battery (0x01)
// < temperature (0x02).
// ---------------------------------------------------------------------------
#define BTHOME_UUID16_LO      0xD2   // 0xFCD2, little-endian
#define BTHOME_UUID16_HI      0xFC
#define BTHOME_DEVICE_INFO    0x40   // unencrypted, regular interval, version 2

#define BTHOME_ID_PACKET_ID   0x00
#define BTHOME_ID_BATTERY     0x01
#define BTHOME_ID_TEMPERATURE 0x02


OneWire oneWire(ONEWIRE_PIN);
DallasTemperature sensors(&oneWire);

uint8_t packetId = 0;

void setup() {
  analogReadResolution(14);

  sensors.begin();

  // First conversion right after begin() reliably reads -127
  // (DEVICE_DISCONNECTED_C) on this sensor - throw away one reading here so
  // loop()'s first real reading is valid.
  sensors.requestTemperatures();
  sensors.getTempCByIndex(0);

  Bluefruit.begin();
  Bluefruit.setName("FreezerMonitor");
  Bluefruit.setTxPower(8);  // nRF52840 max; helps punch through freezer lid attenuation
  pinMode(38, OUTPUT);     // P1.06 = 32 + 6, per your variant map
  digitalWrite(38, HIGH);
}

void loop() {
  float tempC = readTemperatureC();
  float battV = readBatteryVoltage();
  uint8_t batteryPct = readBatteryPercent(battV);

  sendBTHomeAdvertisement(tempC, batteryPct);
  delay(ADVERTISE_DURATION_MS);
  Bluefruit.Advertising.stop();

  delay(SLEEP_INTERVAL_MS);
}

// Returns DallasTemperature's DEVICE_DISCONNECTED_C (-127.0) if the DS18B20
// can't be read. That gets encoded into the BTHome payload as-is (an obviously
// out-of-range freezer temperature) rather than silently sending a stale or
// fabricated value - see project notes on failure alerting.
float readTemperatureC() {
  sensors.requestTemperatures();
  return sensors.getTempCByIndex(0);
}

// Averages a few samples from the external divider on BATT_ADC_PIN to smooth
// out the ~1% ADC noise observed during calibration.
float readBatteryVoltage() {
  const int numSamples = 8;
  uint32_t total = 0;
  for (int i = 0; i < numSamples; i++) {
    total += analogRead(BATT_ADC_PIN);
    delay(2);
  }
  float avgRaw = (float)total / numSamples;
  return avgRaw * BATT_SCALE;
}

uint8_t readBatteryPercent(float battV) {
  float pct = (battV - BATT_EMPTY_V) / (BATT_FULL_V - BATT_EMPTY_V) * 100.0f;
  if (pct > 100.0f) pct = 100.0f;
  if (pct < 0.0f) pct = 0.0f;
  return (uint8_t)round(pct);
}

void sendBTHomeAdvertisement(float tempC, uint8_t batteryPct) {
  int16_t tempRaw = (int16_t)round(tempC * 100.0f);

  uint8_t payload[] = {
    BTHOME_UUID16_LO, BTHOME_UUID16_HI,
    BTHOME_DEVICE_INFO,
    BTHOME_ID_PACKET_ID, packetId++,
    BTHOME_ID_BATTERY, batteryPct,
    BTHOME_ID_TEMPERATURE, (uint8_t)(tempRaw & 0xFF), (uint8_t)((tempRaw >> 8) & 0xFF),
  };

  Bluefruit.Advertising.clearData();
  Bluefruit.Advertising.addFlags(BLE_GAP_ADV_FLAGS_LE_ONLY_GENERAL_DISC_MODE);
  Bluefruit.Advertising.addData(BLE_GAP_AD_TYPE_SERVICE_DATA, payload, sizeof(payload));

  // Interval units are 0.625ms; 160 = 100ms.
  Bluefruit.Advertising.setInterval(160, 160);
  Bluefruit.Advertising.start(0); // 0 = no timeout; stopped manually after ADVERTISE_DURATION_MS
}

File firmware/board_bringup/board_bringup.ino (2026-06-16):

/*
 * Board Bring-up - P0.13 rail-switch + identity test
 * Teyleten Pro Micro nRF52840 (nice!nano v2 clone)
 *
 * Runs entirely on battery (B+/B-) - no USB, no serial monitor needed.
 * LED (PIN_LED1 / onboard blue LED) signals which phase is active.
 *
 * Loops forever:
 *   Phase 1 - P0.13 LOW, LED OFF, 10s
 *     -> multimeter: red lead on VCC (right side, pos 9), black on any GND
 *   Phase 2 - P0.13 HIGH, LED ON, 10s
 *     -> multimeter: read VCC again, compare to phase 1
 *     (these two phases tell us P0.13's rail-switch polarity, if any)
 *   Phase 3 - P0.13 held LOW, LED rapid-flashing, 30s
 *     -> multimeter: red lead on right side positions 3, 4, 5 in turn
 *        (black on any GND) - whichever reads ~0V is the pin physically
 *        wired to P0.13. The other two are SPI pins (P1.11/P1.13) and
 *        should float/read unstable.
 *
 * CONFIRMED 2026-06-15: P0.14 and P0.16 hang/crash-loop the board as soon as
 * either is configured as GPIO - neither is used here.
 */

#include <Arduino.h>

#define SENSOR_PWR_PIN 13

void setup() {
  pinMode(SENSOR_PWR_PIN, OUTPUT);
  pinMode(PIN_LED1, OUTPUT);
}

void loop() {
  // Phase 1: P0.13 LOW, LED off - read VCC
  digitalWrite(SENSOR_PWR_PIN, LOW);
  digitalWrite(PIN_LED1, !LED_STATE_ON);
  delay(10000);

  // Phase 2: P0.13 HIGH, LED on - read VCC again
  digitalWrite(SENSOR_PWR_PIN, HIGH);
  digitalWrite(PIN_LED1, LED_STATE_ON);
  delay(10000);

  // Phase 3: P0.13 held LOW, LED rapid-flash - identify which physical pin
  // (right side 3, 4, or 5) is actually P0.13
  digitalWrite(SENSOR_PWR_PIN, LOW);
  uint32_t phaseStart = millis();
  while (millis() - phaseStart < 30000) {
    digitalWrite(PIN_LED1, LED_STATE_ON);
    delay(100);
    digitalWrite(PIN_LED1, !LED_STATE_ON);
    delay(100);
  }

  // Reboot - starts the whole cycle over from a clean reset
  NVIC_SystemReset();
}

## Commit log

2026-06-16 Updating Claude and Readme's to represent current state
2026-06-16 work in progress
    [1011.step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]
2026-06-17 Project directory cleanup, removing unneccessary code related to rotating footprints
    [1011.step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]
